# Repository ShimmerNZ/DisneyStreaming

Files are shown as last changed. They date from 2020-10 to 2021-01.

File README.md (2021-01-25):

# DisneyStreaming
 Raspi Network Bonding UI with Speedify
 
 The purpose of this project was to look at a way of building a device that could leverage multiple network interfaces (specifically mobile and wifi) to create a more stable network
 for IRL streaming. The commercially available products were very expensive starting at $1k US and going up from there. The concept does require a server end component to aggregate the
 traffic and forward on. I initially looked at some options to host and do this myself but came across the speedify product which was a subscription service and all done for me. 
 For clarity I am not affiliated with Speedify in any way shape or form. After some initial testing to verifify throughput which was one of my concerns... like is this service going
 to be throttled to heck? The results were pleasing and was getting upwards of 300mbps up/down over a wifi connected device to a non dedicated speedify server. 
 This was way more than enough for IRL streaming so continued to progress. This project was purpose built for a Disney streamer but could be easily customisable for any other purpose
 UI is built in Python3 using Tkinter. I originally started with a pihat touch screen but dropped it for 2 reasons:
 * UI/Resolution was too small, and limited room to display much, this was also going to be a problem with initial setup to display wifi captive portal screens
 * Capacitive touch screen sucked
 I found the Speedify app was resource intensive especially when interface disconnected where it would consume 200% resource causing the Pi to overheat.
 I decided to build a seperate UI to control it as well as show up signal strength. Everythign else leverages the speedify back end.

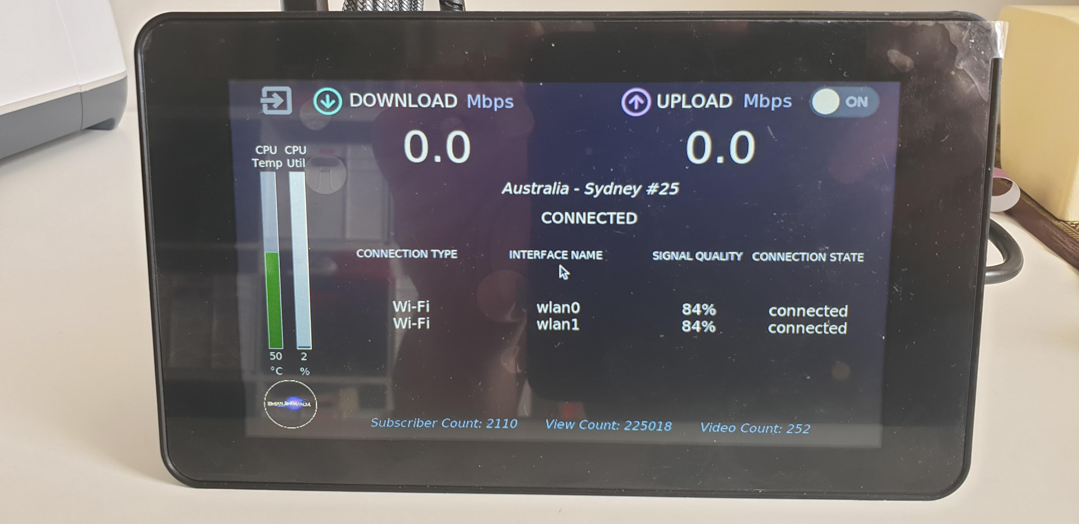
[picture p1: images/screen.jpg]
Front
 
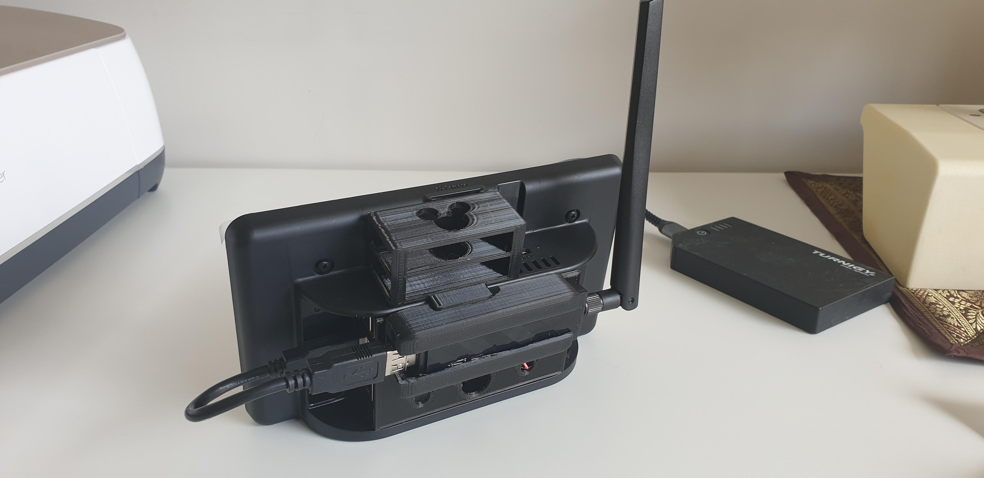
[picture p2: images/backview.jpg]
Back view
 

 Parts List
 ===========
 * Raspberry Pi4b - 2GB is fine
 * SD card
 * Official Raspberry pi 7 inch touchscreen
 * Neego Raspi 4 Screen case for Raspi Monitor Touchscren Display 7" - https://www.amazon.com/gp/product/B081VT2CPW/
 * Power supply - The official 3a power supply worked fine. I've also run it off battery pack just use a decent USB c cable with heavy gauge wire for power. 21awg worked for me

 To attach the dongles I created a custom back plate which I 3d printed. The STL files for that are included in the repo also.

Install Process
================
Install fresh install of 32bit Raspberry pi Desktop OS with Desktop (built using Buster on a Raspi4b) - I used the Raspberry Pi Imager software to do this  
https://www.raspberrypi.org/downloads/  
or for just the iso image  
https://www.raspberrypi.org/downloads/raspberry-pi-os/  

## Power up Device, setup wifi and update it
 Setup location/password/wifi through desktop UI wizard
 ```
 sudo raspi-config and enable SSH
 ```
 ### Alternative manual method
 ```
 sudo apt-get update
 sudo apt-get upgrade
 restart
 ```

## Install Speedify  
 ```
 wget -qO- https://get.speedify.com | sudo -E bash -
 sudo apt-get install speedifyui
 sudo nano /etc/speedify/speedify.conf
 ```
 Add/Enable the following
 ```
 ENABLE_SHARE=1  
 SHARE_INTERFACE="eth0"  
 SHARE_WITHOUT_SPEEDIFY=1
 ```
 Save and Exit 
 ```
 sudo service speedify-sharing restart
 ```

## Add iPhone support & Autostart
 ```
 sudo apt install usbmuxd
 /usr/share/speedify/speedify_cli startupconnect on
 ```

## Install USB Wifi driver - only for AC56 device  
 ```
 cd /home/pi
 sudo apt-get install bc raspberrypi-kernel-headers
 sudo apt-get install dkms
 git clone -b v5.7.0 https://github.com/aircrack-ng/rtl8812au.git
 cd rtl*
 sed -i 's/CONFIG_PLATFORM_I386_PC = y/CONFIG_PLATFORM_I386_PC = n/g' Makefile
 sed -i 's/CONFIG_PLATFORM_ARM64_RPI = n/CONFIG_PLATFORM_ARM64_RPI = y/g' Makefile
 sed -i 's/^dkms build/ARCH=arm dkms build/' dkms-install.sh
 sed -i 's/^MAKE="/MAKE="ARCH=arm\ /' dkms.conf
 sudo ./dkms-install.sh
 ```

## Clone streaming repo and do the install  
 ``` 
 git clone https://github.com/ShimmerNZ/DisneyStreaming
 cd DisneyStreaming
 chmod +x update.sh
 cp /home/pi/DisneyStreaming/update.sh /home/pi/update.sh
 run update .sh
 mkdir /home/pi/logs
 mkdir /home/pi/.config/autostart
 pcmanfm --set-wallpaper /home/pi/DisneyStreaming/images/desktop.png

 sudo cp /home/pi/DisneyStreaming/images/splash.png /usr/share/plymouth/themes/pix/splash.png  
 ```

## Install software keyboard  
 ```
 sudo apt-get install matchbox-keyboard
 ``` 
## Install some Python library dependancies  
 ``` 
 sudo apt-get install python3-pil python3-pil.imagetk
 ```

## Install official raspberry pi 7"inch touchscreen"  
 ```
 sudo nano /boot/config.txt
 ```
 add the following at the bottom  
 ```
 disable_splash=1
 lcd_rotate=2
 max_usb_current=1
 ```

## modify boot process to remove the raspbery pi stuff                                                                                
 ```
 sudo nano /boot/cmdline.txt
 ```
 append the following to the end  
 ```
 quiet splash loglevel=0 logo.nologo
 ```

## AC56 Wifi fix  
 ```
 sudo systemctl edit --force --full wificheck.service 
 ```
 copy contents from wificheck.service to this file save and exit
 ``` 
 systemctl enable wificheck.service
 sudo systemctl start wificheck.service
 ```
 fix power saving
 ```
 sudo nano /etc/rc.local
 ```
 add the following before exit 0
 ```
 /sbin/iw dev wlan1 set power_save off
 ```

## File Manager changes 
 * Open File Manager --> Edit --> Preferences --> General  --> tick "Open files with single click"  
 * Open File Manager --> Edit --> Preferences --> General  --> tick "Don't ask options on launch executeabe file"  
 * Open File Manager --> Edit --> Preferences --> Volume Management  --> untick "Show availabkle options for removeable media when they are inserted"  

## Speedify UI changes
 * Set bonding mode to streaming  
 * Set Disconnect on Exit to Off  
 * Transport mode UDP  
 * Fastest Server

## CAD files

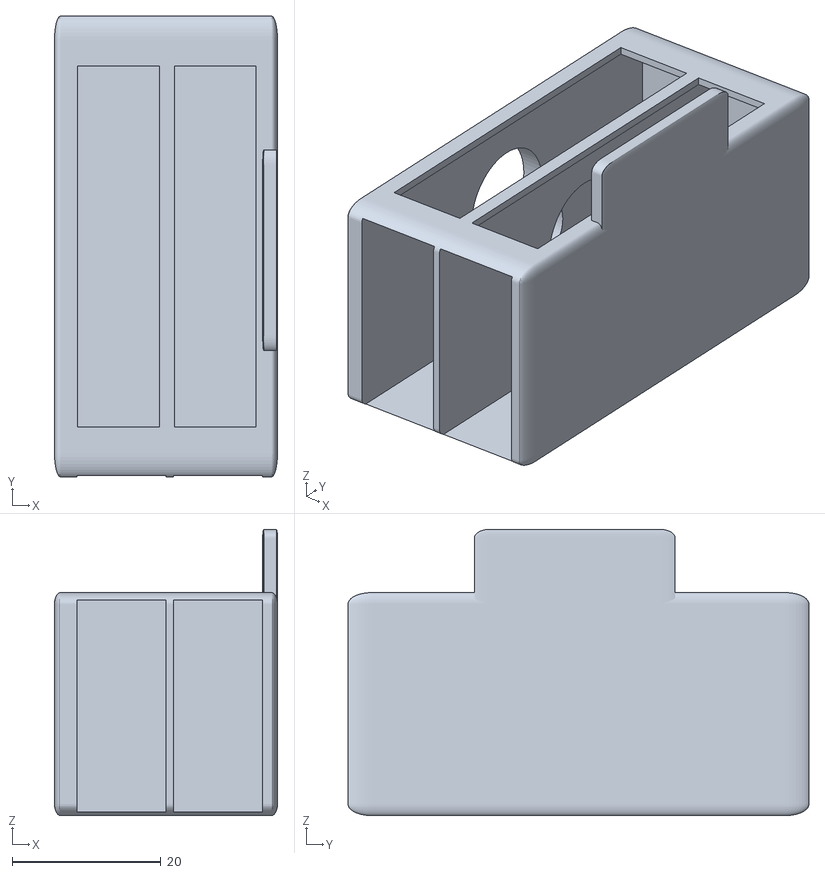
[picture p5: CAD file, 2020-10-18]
STL Files/double usb modem holder.stl
30.0 x 62.0 x 38.5

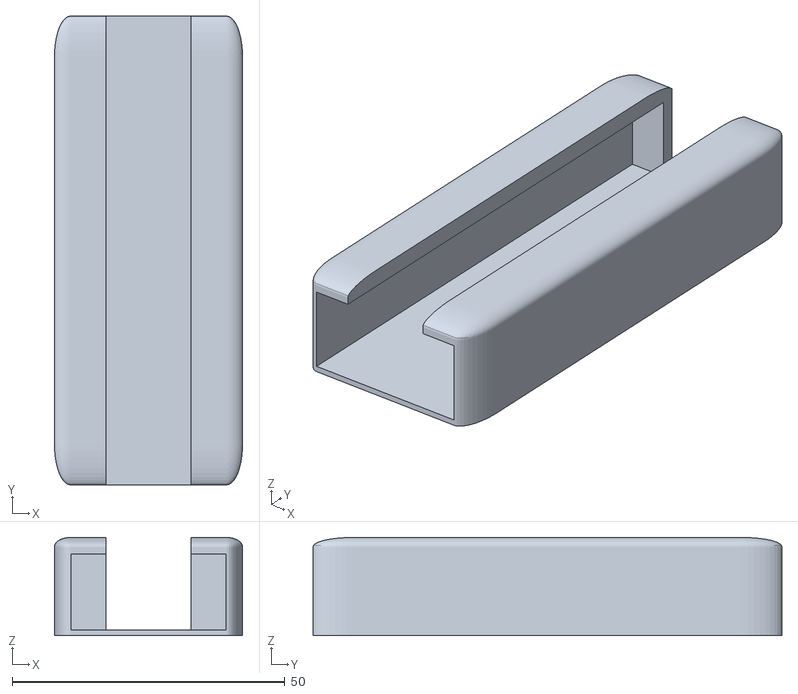
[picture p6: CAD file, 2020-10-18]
STL Files/Asus AC56 wifi holder.stl
34.5 x 86.0 x 18.0

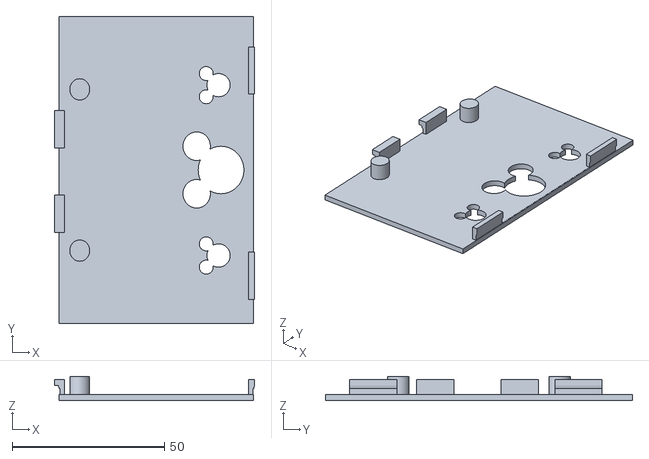
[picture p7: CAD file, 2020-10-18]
STL Files/backplate.stl
65.8 x 101.0 x 8.00

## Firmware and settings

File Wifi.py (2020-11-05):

#!/usr/bin/python
import os
import subprocess
import time

time.sleep(300)

while True:
    try:
        ps=subprocess.Popen("ip link list wlx244bfe3a2a5c", shell=True, stdout=subprocess.PIPE, stderr=subprocess.STDOUT)
        output = subprocess.check_output(('grep','NO-CARRIER'),stdin=ps.stdout)
        print(output, flush=True)
        if 'NO-CARRIER' in output:
            os.system('sudo ip link set wlx244bfe3a2a5c down')
            os.system('sudo ip link set wlx244bfe3a2a5c up')
            time.sleep(30)
        else:
            time.sleep(30)
            #print("network ok", flush=True)
    except subprocess.CalledProcessError:
        time.sleep(30)
        #print("network ok", flush=True)

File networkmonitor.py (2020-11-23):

#!/usr/bin/python3
# Monitoring App so that you can see the status of the various interfaces, connectivity status, throughput, CPU utilisation and temp
# of the Raspberry Pi
# include speed test function - speedtest-cli
# show IP address
# captive portal launch?
# enable/disable speedify


from gpiozero import CPUTemperature
from tkinter import ttk
from PIL import Image, ImageTk
import time
import tkinter as tk
import speedify
import urllib.request
import json
import re
import requests
import os
import subprocess
import argparse
import psutil
import urllib.request
import threading
import multiprocessing


interface ="wlan0" # this is just a sample value


#import stuff I don't want to load into github
try:
    from secrets import secrets
    #print(secrets)
except ImportError:
    print('failed to read secrets file containing Youtube API key', flush=True)
    raise

#CPU Temp Section
cpu=CPUTemperature()
global tx_prev
global rx_prev
(tx_prev,rx_prev)=(0,0)
#Speedify settingssudo apt-get install python3-pil python3-pil.imagetk

class PopUpConfirmQuit(tk.Toplevel):
    """A TopLevel popup that asks for confirmation that the user wants to quit.
    Upon confirmation, the App is destroyed.
    If not, the popup closes and no further action is taken
    """
    def __init__(self, master=None):
        super().__init__(master)
        tk.Label(self, text="What would you like to do?").pack()
        tk.Button(self, text='Exit App', command=self.Exit, fg='green').pack(side=tk.RIGHT, fill=tk.BOTH, padx=5, pady=5)
        tk.Button(self, text='Cancel', command=self.destroy).pack(side=tk.RIGHT, fill=tk.BOTH, padx=5, pady=5)
        tk.Button(self, text='Restart', command=self.Reboot, fg='red').pack(side=tk.RIGHT, fill=tk.BOTH, padx=5, pady=5)
        tk.Button(self, text='Shutdown', command=self.Shutdown, fg='red').pack(side=tk.RIGHT, fill=tk.BOTH, padx=5, pady=5)
    
    def Shutdown(self):
        os.system('shutdown -h now')

    def Reboot(self):
        os.system('reboot')

    def Exit(self):
        exit()
 
class PopUpReconnect(tk.Toplevel):
    """A TopLevel popup that asks for confirmation that the user wants to quit.
    Upon confirmation, the App is destroyed.
    If not, the popup closes and no further action is taken
    """
    def __init__(self, arg, master=None):
        super().__init__(master)
        tk.Label(self, text="What would you like to do?").pack()
        tk.Button(self, text='Connect', command=lambda: self.reconnect(arg), fg='green').pack(side=tk.RIGHT, fill=tk.BOTH, padx=5, pady=5)
        tk.Button(self, text='Cancel', command=self.destroy).pack(side=tk.RIGHT, fill=tk.BOTH, padx=5, pady=5)
        #tk.Button(self, text='Reset Wifi', command=self.resetwifi, fg='orange').pack(side=tk.RIGHT, fill=tk.BOTH, padx=5, pady=5)
        tk.Button(self, text='Reset Network', command=self.resetnetwork, fg='red').pack(side=tk.RIGHT, fill=tk.BOTH, padx=5, pady=5)
        tk.Button(self, text='Disconnect', command=lambda: self.disconnect(arg), fg='red').pack(side=tk.RIGHT, fill=tk.BOTH, padx=5, pady=5)
    
    def reconnect(self, arg):
        arg['image']= imgon
        speedify.connect_closest()
        self.destroy()

    def disconnect(self, arg):
        arg['image']= imgoff
        speedify.disconnect()
        self.destroy()

    def resetwifi(self):
        os.system('sudo ip link set wlan1 down')
        os.system('sudo ip link set wlan1 up')
        self.destroy()

    def resetnetwork(self):
        os.system('sudo systemctl daemon-reload')
        os.system('sudo systemctl restart dhcpcd')
        self.destroy()

class Mainframe(tk.Frame):
    def __init__(self,master,*args,**kwargs):
        tk.Frame.__init__(self,master,*args,**kwargs)

        self.configure(bg='#0b0c1b')


        #CPU headins
        self.TemperatureC = tk.IntVar()
        tk.Label(self,textvariable = self.TemperatureC,bg='#0b0c1b',fg='#fff', font=("HCo Gotham SSm",10)).grid(row=18, column=1)
        TempHeading='CPU'+'\n'+'Temp'
        tk.Label(self,text=TempHeading,bg='#0b0c1b',fg='#fff', font=("HCo Gotham SSm",10) ).grid(row=2, column=1, sticky='S', rowspan=2)
        tk.Label(self,text='°C',bg='#0b0c1b',fg='#fff', font=("HCo Gotham SSm",10) ).grid(row=21, column=1)

        self.CPUutil=tk.IntVar()
        tk.Label(self,textvariable = self.CPUutil,bg='#0b0c1b',fg='#fff', font=("HCo Gotham SSm",10)).grid(row=18, column=2)
        CPUHeading='CPU'+'\n'+'Util'
        tk.Label(self,text=CPUHeading,bg='#0b0c1b',fg='#fff', font=("HCo Gotham SSm",10) ).grid(row=2, column=2, sticky='S', rowspan=2)
        tk.Label(self,text='%',bg='#0b0c1b',fg='#fff', font=("HCo Gotham SSm",10)).grid(row=21, column=2)


        #Server Details
        self.Currentserver = tk.StringVar()
        tk.Label(self,textvariable=self.Currentserver,bg='#0b0c1b',fg='#fff',font=("HCo Gotham SSm",14,"italic")).grid(row=4, column=3, columnspan=6)

        self.Connectionstate = tk.StringVar()
        tk.Label(self,textvariable=self.Connectionstate,bg='#0b0c1b',fg='#fff',font=("HCo Gotham SSm",14)).grid(row=5, column=3, columnspan=6)

        #download stats
        img=tk.PhotoImage(file='/home/pi/DisneyStreaming/images/down.gif')
        img2=tk.PhotoImage(file='/home/pi/DisneyStreaming/images/up.gif')
        lbl=tk.Label(self, image=img2, bg='#0b0c1b')
        lbl.image = img2
        lbl.grid(row=1, column=3)
        lbl=tk.Label(self, image=img, bg='#0b0c1b')
        lbl.image = img
        lbl.grid(row=1, column=6)

        tk.Label(self,text='     UPLOAD ',bg='#0b0c1b',fg='#fff', font=("HCo Gotham SSm",16)).grid(row=1, column=4)
        tk.Label(self,text='Mbps', bg='#0b0c1b',fg='#9193a8', font=("HCo Gotham SSm",16)).grid(row=1, column=5, sticky='W')
        tk.Label(self,text='DOWNLOAD ', bg='#0b0c1b',fg='#fff', font=("HCo Gotham SSm",16)).grid(row=1, column=6, columnspan=2, sticky='E')
        tk.Label(self,text='Mbps', bg='#0b0c1b',fg='#9193a8', font=("HCo Gotham SSm",16)).grid(row=1, column=8, columnspan=2, sticky='W')

        self.TXspeed = tk.StringVar()
        tk.Label(self,textvariable=self.TXspeed , bg='#0b0c1b',fg='#fff', font=("HCo Gotham SSm",40)).grid(row=2, column=3, rowspan=2, columnspan=3)
        self.RXspeed = tk.StringVar()
        tk.Label(self,textvariable=self.RXspeed , bg='#0b0c1b',fg='#fff', font=("HCo Gotham SSm",40)).grid(row=2, column=6, rowspan=2, columnspan=3)

        #Adapter Stats
        tk.Label(self,text='CONNECTION TYPE  ', bg='#0b0c1b',fg='#fff', font=("HCo Gotham SSm",10)).grid(row=7, column=4)
        tk.Label(self,text='INTERFACE NAME  ', bg='#0b0c1b',fg='#fff', font=("HCo Gotham SSm",10)).grid(row=7, column=5, columnspan=2, padx=50 )
        tk.Label(self,text='SIGNAL QUALITY  ', bg='#0b0c1b',fg='#fff', font=("HCo Gotham SSm",10)).grid(row=7, column=7)
        tk.Label(self,text='CONNECTION STATE  ', bg='#0b0c1b',fg='#fff', font=("HCo Gotham SSm",10)).grid(row=7, column=8)
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

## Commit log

2020-10-07 removed transparency and fixed on/off image toggle
    [networkmonitor.py]
2020-10-18 added 3d print files
    [Asus AC56 wifi holder.stl, backplate.stl, double usb modem holder.stl]
